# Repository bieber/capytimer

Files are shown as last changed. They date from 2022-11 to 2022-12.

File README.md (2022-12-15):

# CapyTimer

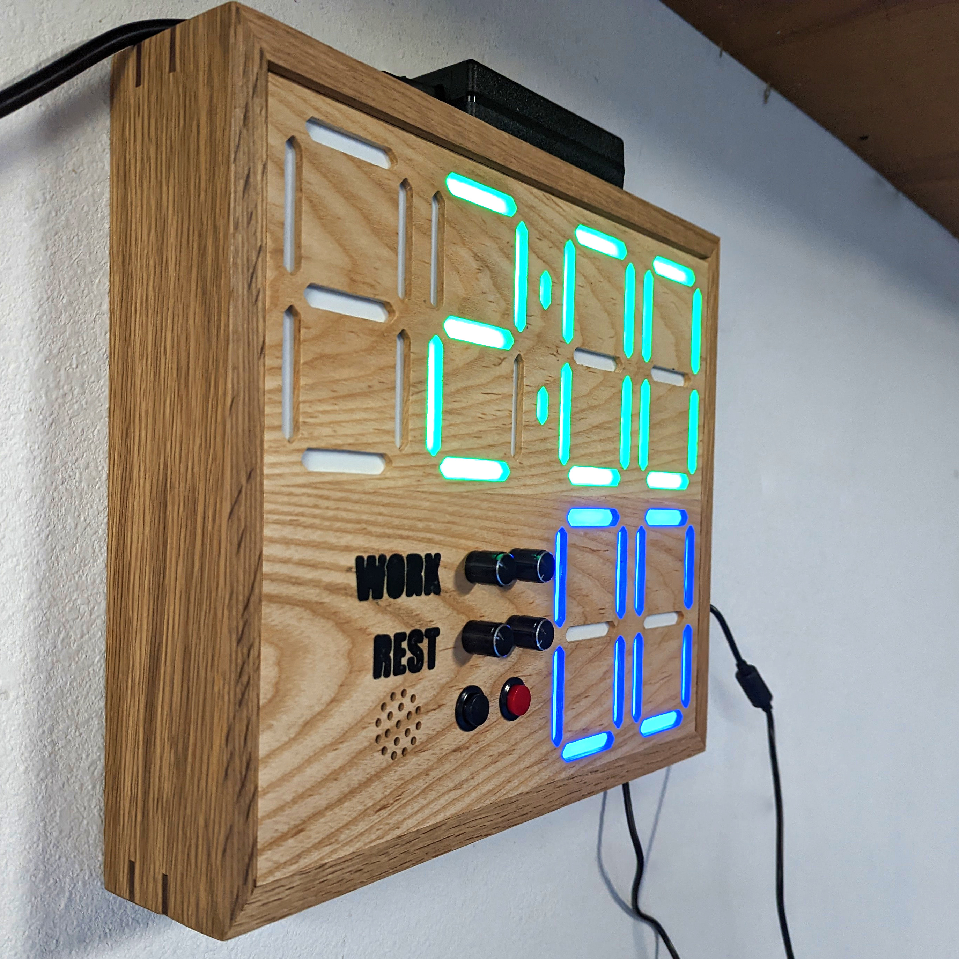
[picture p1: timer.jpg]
Photo of the completed timer


CapyTimer is meant to be a simple timer for
boxing/kickboxing/grappling/fitness.  My goal is to keep its interface
as simple as possible while maintaining the most important
functionality.  Work and rest times are set with dials, and the timing
started and stopped with a switch or button.  The display counts the
remaining time, the current round, and nothing else.

The display is constructed from WS2812B addressable LEDs.  The
original plan was to cut up and solder three-LED sections to create
the digits, but that proved time consuming and ugly so I ultimately
designed a PCB for the digits with the LEDs pre-placed.  You can
follow the original plan and save some money by cutting up and
soldering a WS2812B strip, or just order the PCBs preassembled from
JLC (or just get the boards manufactured and solder on the LEDs
yourself).

This isn't really meant to be a prescriptive set of instructions for
building the timer exactly a certain way.  I've provided components
here and I'll lay out a general path towards putting it together, but
you should feel free to substitute different controls and alter the
presentation to your liking.

**Warning** - The remote control design is currently untested.  I
*think* the parts will all fit properly, but I'm still waiting on the
final PCBs to test with and can't guarantee that the design works yet.

## Directory Structure

* `3d/` - Files for 3D printing.  These include the digit and
  separator diffusers, the remote control body, and a set of printed
  frames to hold the digits for testing purposes.
* `firmware/` - Code to run the AVR microcontroller.  Specifically
  this expects an Atmega328P, the avr-gcc toolchain and a USBasp
  programmer.  If you deviate from these specifications you may need
  to alter the firmware and makefile.
* `pcb/` - KiCad schematics and PCB designs.  This includes the main
  control board, boards with the LEDs laid out for the digits and
  separator, and a control board for the remote control.  With the
  exception of the remote control board (which is simple enough to
  easily hand solder), I've included gerbers and BOM/placement files
  that you can use to have the boards manufactured by JLCPCB.  These
  worked as of this publishing, but be warned that some parts may go
  out of stock and need replacing (they already switched to a new
  version of the WS2812B LEDs while I was working on the boards).
* `enclosure` - SVG designs to cut a front for the timer using the
  Shaper Origin.  You'll have to adapt these if you use a different
  CNC.

## Assembly Instructions

Please don't consider these instructions exhaustive, but more general
guidance.  You'll want to have some experience with electronics,
soldering and crimping connectors before getting started on this, as
well as some way to build an enclosure for the timer (I build mine out
of wood).

### Materials

| Part | Qty |
| ---- | --- |
| Control Board | 1 |
| Digit Board | 6 |
| Separator Board | 1 |
| Digit Diffuser | 6 |
| Separator Diffuser | 1 |
| M3x4.6x5.7mm Heat Set Inserts | 17 |
| M3x6 Screw | 14 |
| Linear Potentiometer (somewhere in the neighborhood of 10k) | 4 |
| Push Button | 2 |
| JST-PH Connector (3 pin) | 20 |
| JST-PH Connector (2 pin) | 4 |
| DC Barrel Connector | 1 |
| Right Angle Header (Female, 2.54mm) | 14 pins |
| Header (Male, 2.54mm) | 3 pins |
| Header Jumper | 1 |
| AVR-ISP 6 Pin Box Header | 1 |
| 3386P Potentiometer | 2 |
| 10k Through Hole Resistor | 2 |
| QIACHIP 433Mhz Transmitter/Receiver Set | 1 |
| Remote Control Parts | 1 set |
| M3x12 Screw | 3 |
| 5x1mm Round Magnet | 8 |
| AAA Battery Contact Plate | 4 |

Note that this doesn't include surface-mount components on the PCB,
only the parts you'll need to manually assemble.  If you intend to
hand solder the PCBs, consult the schematics for part listings.

### The Display

The display uses six digits and one separator between the minutes and
seconds.  You can have the digits and separator LEDs pre-assembled on
a PCB by JLCPCB using the files in the `pcb/` directory, or you can
buy a strip of WS2812B LEDs and glue them into the 3D printed
diffusers.  If you do so, you'll want to use 3 LEDs per digit segment
and one for each of the dots in the separator.  The LEDs should be
laid out in the same order that segments normally come in a seven
segment display.

If you get your LED PCBs pre-assembled, you'll still need to solder on
the connectors.  Use one three-pin JST-PH connector for each
connection.  Be sure to solder these on the back side of the board so
you can plug in to them while the front of the board is seated in the
diffuser.

When printing the plastic diffusers, I like to use white filament for
the first few layers and then switch to black.  This will minimize
light bleeding between segments while the display is in use.  If you
use PCBs for the digits and separator, the diffusers have holes for
threaded inserts.  You can then use the M3x6 screws to attach the
boards to the diffusers.

### The Control Board

Assuming you get the control board assembled by JLCPCB or some other
manufacturer, you'll just need to solder the connectors and a few
potentiometers onto the control board.  These include the DC barrel
jack for power, JST-PH connections for the screen, potentiometers and
push buttons, the AVR-ISP header, the header for the diagnostic jumper
(optional) and the angled header for the QIACHIP receiver module
(optional, only required if you want to use the remote control).  The
two 3386P potentiometers are used for volume and brightess control and
should be soldered directly onto the board.

The `JRESET1` connector is currently unused and can be safely ignored.

To program the microcontroller, just connect the ISP header to a
USBasp programmer.  You'll need the avr-gcc toolchain and avrdude
installed.  You can then run `make fuse` to program the fuses on the
chip, and `make program` to transfer the firmware.  After that the
timer should just work when everything is plugged in.

### Connections

* Solder a DC barrel jack connector onto `J1` for power.
* Connect four potentiometers to the 3-pin JST-PH connectors on the
  top-left corner of the board.  These will set the minutes and
  seconds for the work and rest periods.  The names on the silk screen
  are abbreviations for the function of the potentiometer, e.g. `JWM1`
  is the connection for the potentiometer that controls the minutes of
  the work period.  For these connectors, pin 1 is ground, pin 2 is
  signal, and pin 3 is +5v.
* The display connects to `JOUT1` and `JOUT2` via 3-pin JST-PH
  connectors.  Pin 1 is ground, pin 2 is signal, pin 3 is +5v.  As
  long as you connect the same pins on each end of your cables
  everything should work.  The WS2812B LEDs are daisy chained, so
  `JOUT1` should connect to the `JIN1` connector of the first digit,
  then its `JOUT1` connector should connect to the `JOUT1` of the next
  digit, and so on.  Connect the digits and separator for the time
  first, and then the two digits for the round display.  Finally, you
  can connect `JOUT1` on the last digit to `JOUT2` on the control
  board.  This final connection is for power only, to reduce the
  current that needs to flow through the first connection between
  control board and digits.
* The start and stop buttons should connect to the 2-pin JST-PH
  connectors labeled `JSTART1` and `JSTOP1`.  `JRESET1` is unused.
  These connectors have no polarity, they just need to be normally
  open and close when the buttons are pushed.
* Connect an active piezo buzzer to the 2-pin JST-PH connector labeled
  `JBUZZ1`.
* You may optionally solder a 3 pin male header to `JDIAG1`.  Place a
  jumper across the right two pins for normal operation: shifting the
  jumper to the left will put the timer in diagnostic mode, which
  displays the raw ADC value from the work minutes potentiometer for
  debugging purposes.
* If you intend to use a remote control, solder 7 pin female header,
  preferably right-angle, to `JRF1`.  You can then insert a QIACHIP
  receiver module directly into the header.

### Enclosure

The enclosure is largely left as an exercise for the reader.  You'll
want to select potentiometers and push buttons that fit your desired
aesthetic, and you may also wish to add features like an on/off switch
and external power inlet to the enclosure.

Because of the size of the timer, I haven't included a 3D printed
enclosure design.  Even with a 400x400 print bed, it would be
prohibitive to fit all six digits and the controls.  I have, however,
included two 3D printed frames that can hold the digit diffusers up
(with CA glue).  These aren't suitable for production use, but served
me well during development.

For production use, I build my enclosures as open-backed wooden boxes
with a front panel that has pockets routed in for the digit diffusers,
controls and the piezo buzzer.  I use a Shaper Origin to make the cuts
in the front panel, and you can find the SVG files for my design in
the `enclosure/` directory.  I've only tested these with the Shaper,
and expect that other CNCs will probably need some work to adapt them.

### Remote Control (Optional)

With a QIACHIP receiver and transmitter set, you can also build a
remote control for your timer.  The `pcb/` directory includes a small
PCB to tie the QIACIP transmitter to some tactile push button switches
and two AAA batteries.

For the remote control board, you'll need to solder on two pull-up
resistors, two tactile push-button switches (use switches tall enough
to poke up through the remote body), and a connector for the batteries
(or just solder the battery connectors directly to the board).  Add
right-angle header for the QIACHIP transmitter, and solder on an
antenna to `JANT1`.

The top remote component has holes for three heat-set inserts and four
5x1mm magnets, which should be glued into place.  You'll also want to
glue in the four battery contact plates, alternating positive and
negative plates between the two battery slots.  Solder the two plates
at the bottom of the remote together, and then solder wires on to the
connectors towards the top.

Glue opposite-polarity magnets into the remote lid to hold it on to
the body.  You can then attach the PCB and the remote body bottom to
the top by using the three M3x12 screws.  This connection is
inherently weak because the stems holding everything together are
stressed perpendicular to their layers, so be careful not to tighten
the screws more than necessary to hold everything together.

## Afterword

This should give you a rough idea of how to assemble one of these
timers, but the instructions aren't exceedingly detailed and leave a
lot of room to make the project your own.  If you attempt to build one
and run into problems, feel free to submit an issue.  And if you come
up with a design improvement, pull requests are welcome.

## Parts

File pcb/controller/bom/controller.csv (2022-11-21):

Comment | Designator | Footprint | LCSC
.1uF | C1 | Capacitor_SMD:C_0603_1608Metric | C14663
10uF | C2 | Capacitor_SMD:C_0805_2012Metric | C15850
22pF | C3,C4 | Capacitor_SMD:C_0402_1005Metric | C1555
LED | D1,D2,D3,D4,D5 | LED_SMD:LED_0805_2012Metric | C2297
Barrel_Jack | J1 | Connector_BarrelJack:BarrelJack_Horizontal
AVR-ISP-6 | J2 | Connector_IDC:IDC-Header_2x03_P2.54mm_Vertical
Conn_01x01 | JANT1 | Connector_PinHeader_2.54mm:PinHeader_1x01_P2.54mm_Vertical
Conn_01x02_Male | JBUZZ1,JRESET1,JSTART1,JSTOP1 | Connector_JST:JST_PH_B2B-PH-K_1x02_P2.00mm_Vertical
Conn_01x03_Male | JDIAG1 | Connector_PinHeader_2.54mm:PinHeader_1x03_P2.54mm_Vertical
Conn_01x03_Male | JOUT1,JRM1,JRS1,JWM1,JWS1,JOUT2 | Connector_JST:JST_PH_B3B-PH-K_1x03_P2.00mm_Vertical
Conn_01x07_Female | JRF1 | Connector_PinHeader_2.54mm:PinHeader_1x07_P2.54mm_Vertical
2N7002 | Q1 | Package_TO_SOT_SMD:SOT-23 | C8545
1kΩ | R1,R6,R7,R8,R9 | Resistor_SMD:R_0603_1608Metric | C21190
10kΩ | R2,R3,R4,R5 | Resistor_SMD:R_0603_1608Metric | C25804
R_Potentiometer | RVBRIGHT1,RVVOL1 | Potentiometer_THT:Potentiometer_Bourns_3386P_Vertical
ATmega328P-A | U1 | Package_QFP:TQFP-32_7x7mm_P0.8mm | C14877
Crystal_GND24 | Y1 | Crystal:Crystal_SMD_3225-4Pin_3.2x2.5mm | C431155

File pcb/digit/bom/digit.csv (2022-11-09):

Comment | Designator | Footprint | LCSC
WS2812B | D1,D2,D3,D4,D5,D6,D7,D8,D9,D10,D11,D12,D13,D14,D15,D16,D17,D18,D19,D20,D21 | LED_SMD:LED_WS2812B_PLCC4_5.0x5.0mm_P3.2mm | C2874885
Conn_01x03_Male | JIN1,JOUT1 | Connector_JST:JST_PH_B3B-PH-K_1x03_P2.00mm_Vertical

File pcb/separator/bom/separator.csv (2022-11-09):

Comment | Designator | Footprint | LCSC
WS2812B | D1,D2 | LED_SMD:LED_WS2812B_PLCC4_5.0x5.0mm_P3.2mm | C2874885
Conn_01x03_Male | JIN1,JOUT1 | Connector_JST:JST_PH_B3B-PH-K_1x03_P2.00mm_Vertical

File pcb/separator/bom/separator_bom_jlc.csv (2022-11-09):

Comment | Designator | Footprint | LCSC
WS2812B | D1,D2 | LED_WS2812B_PLCC4_5.0x5.0mm_P3.2mm | C2874885

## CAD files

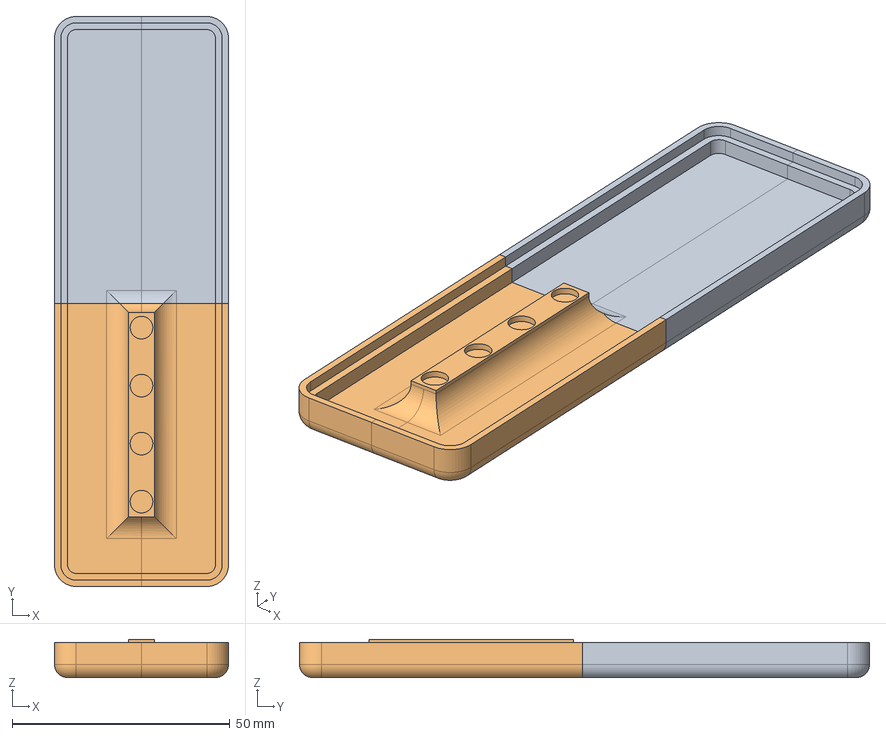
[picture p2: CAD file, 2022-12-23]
3d/remote.FCStd
40.0 x 131.0 x 8.75 mm
Fixed
Lid

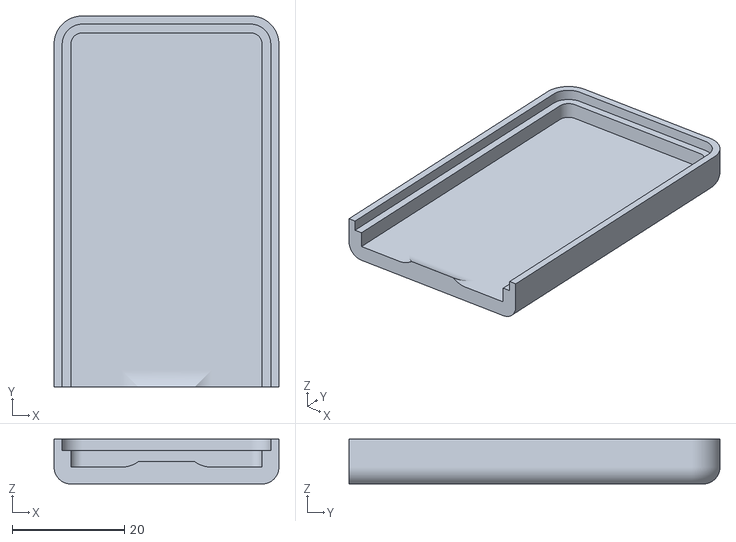
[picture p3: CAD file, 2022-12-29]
3d/stl/remote/bottom.stl
40.0 x 66.0 x 8.00

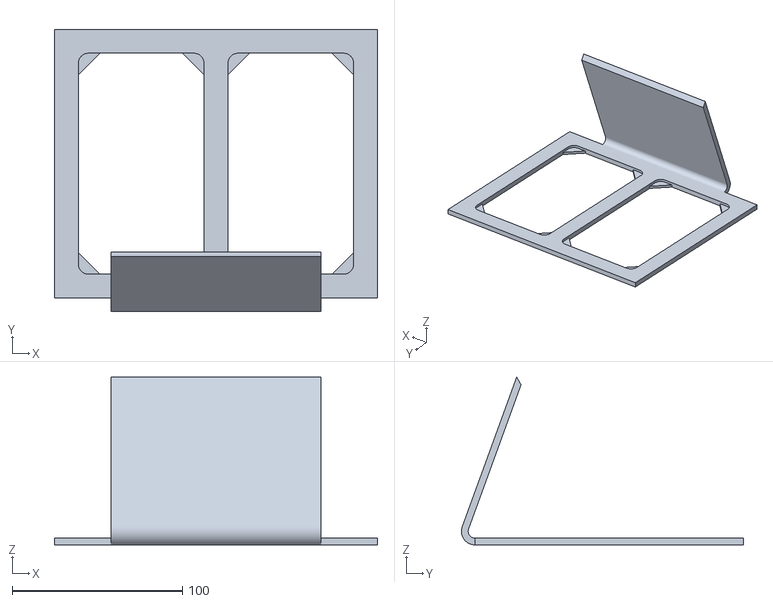
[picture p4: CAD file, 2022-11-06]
3d/stl/round_frame.stl
190.0 x 166.0 x 98.7

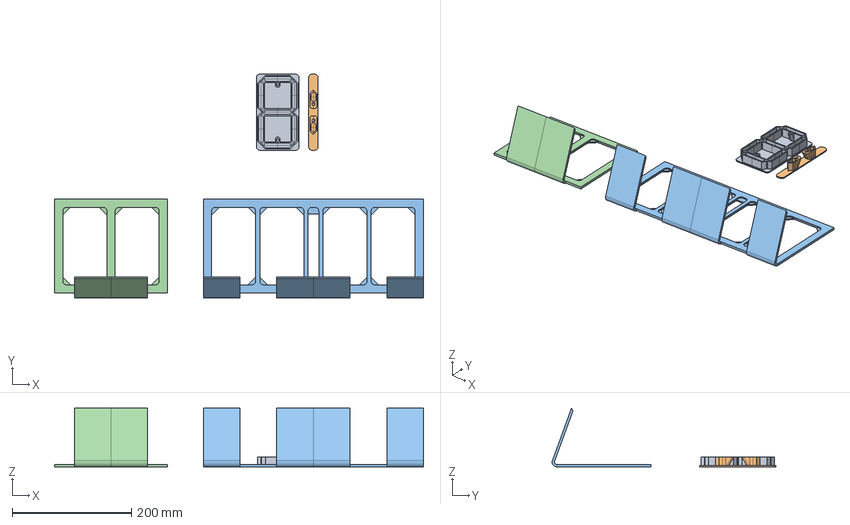
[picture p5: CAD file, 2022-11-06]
3d/capytimer.FCStd
620.0 x 376.0 x 98.7 mm
Digit
Divider
Time Frame
Round Frame

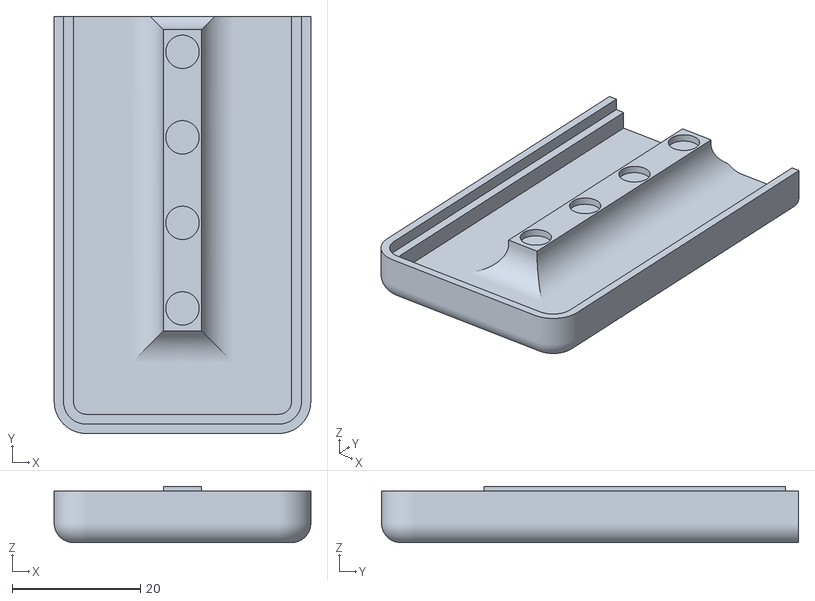
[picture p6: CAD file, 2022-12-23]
3d/stl/remote/lid.stl
40.0 x 65.0 x 8.75

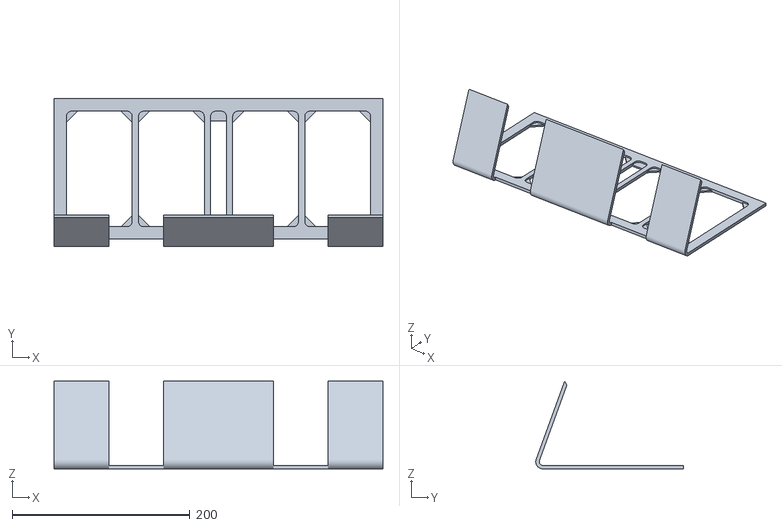
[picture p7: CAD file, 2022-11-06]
3d/stl/time_frame.stl
370.0 x 166.0 x 98.7

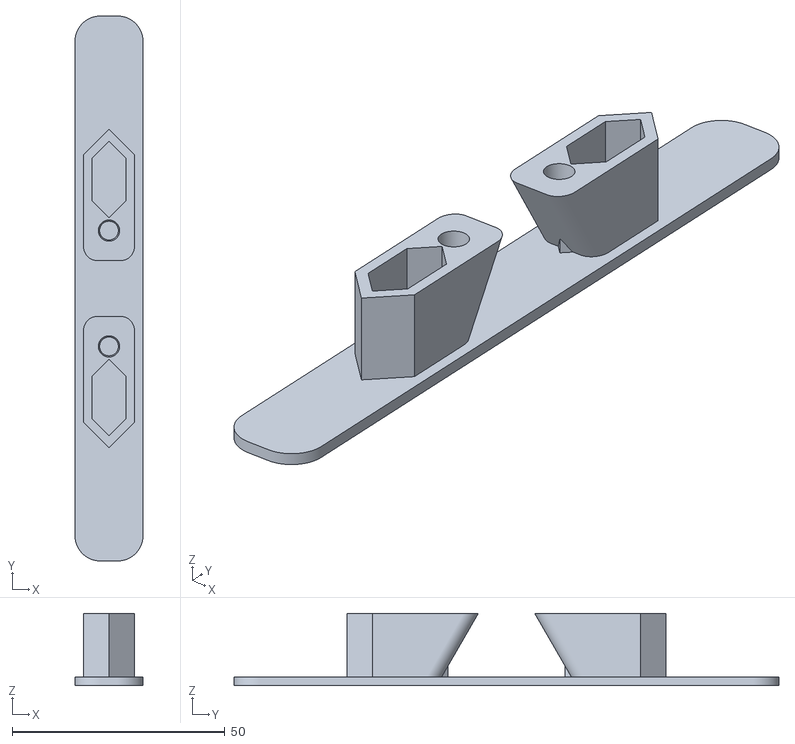
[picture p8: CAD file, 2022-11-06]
3d/stl/divider.stl
16.0 x 128.0 x 17.0

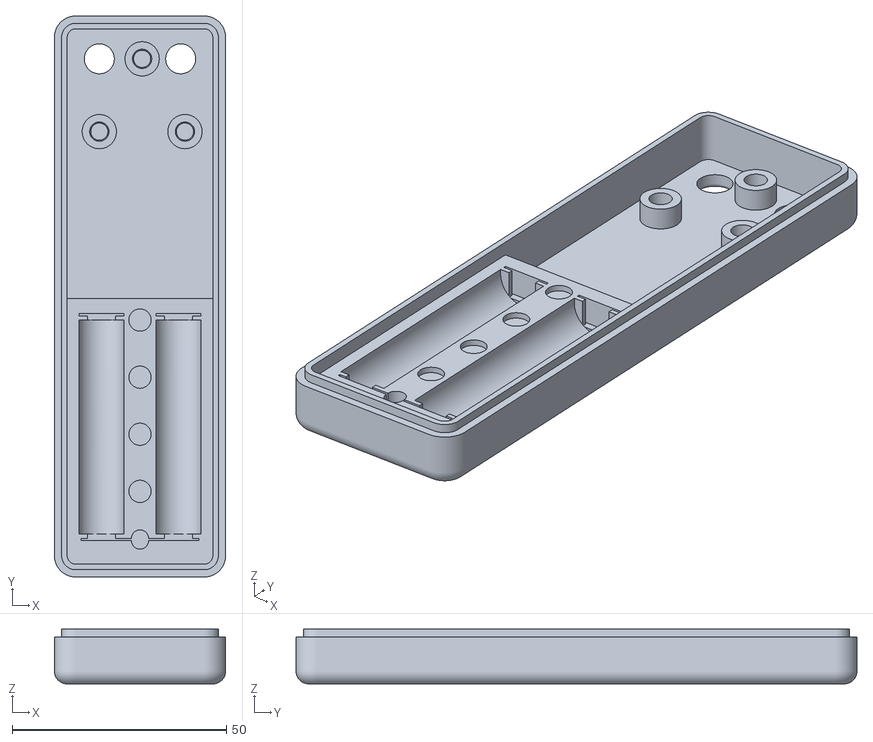
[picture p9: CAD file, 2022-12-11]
3d/stl/remote/top.stl
40.0 x 131.0 x 12.8

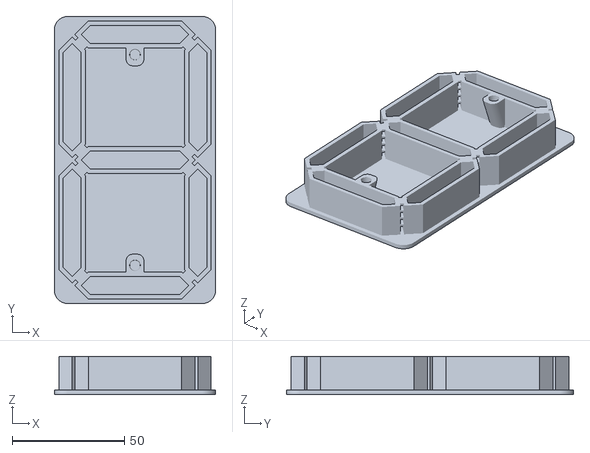
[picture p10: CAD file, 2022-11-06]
3d/stl/digit.stl
72.0 x 128.0 x 17.0

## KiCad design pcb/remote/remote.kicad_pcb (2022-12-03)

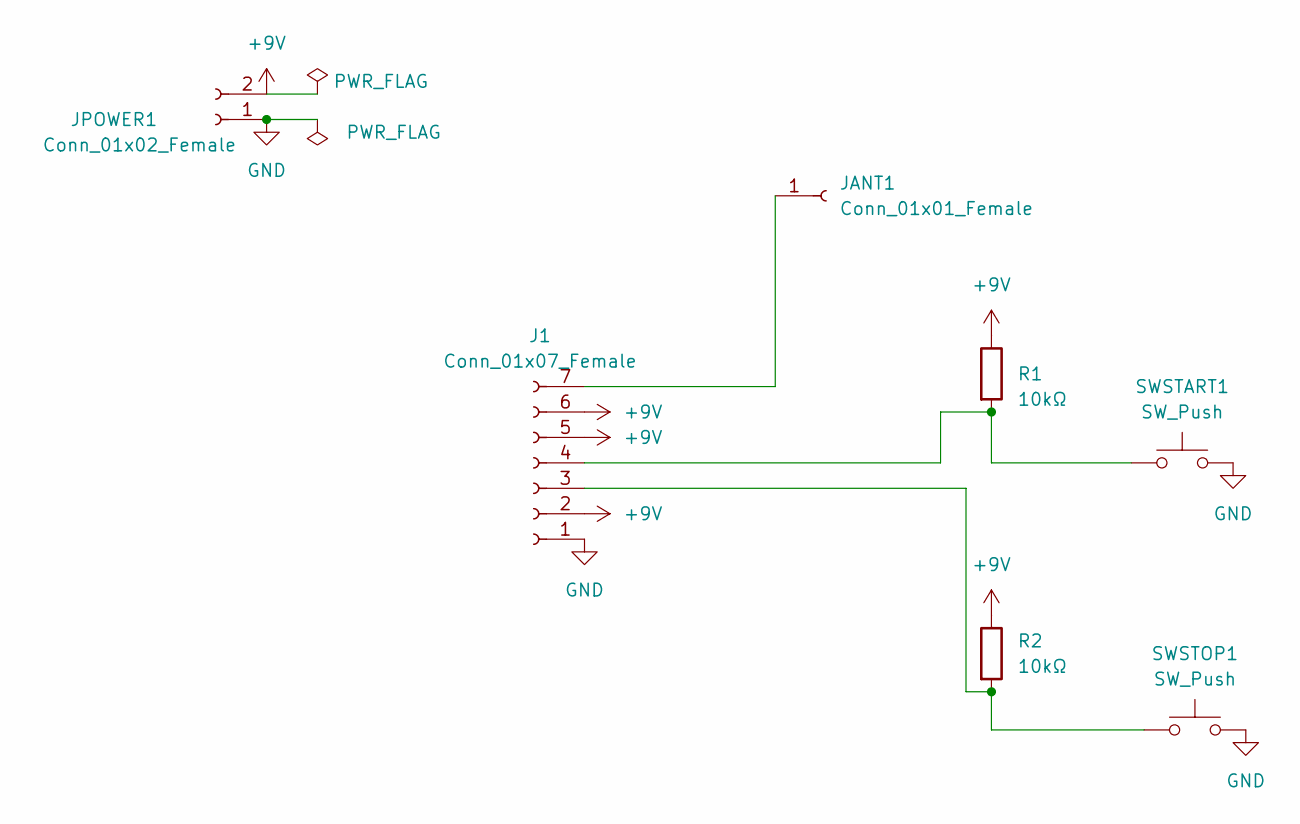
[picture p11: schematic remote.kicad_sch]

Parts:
J1: Conn_01x07_Female; PinHeader_1x07_P2.54mm_Vertical
JANT1: Conn_01x01_Female; PinHeader_1x01_P2.54mm_Vertical
JPOWER1: Conn_01x02_Female; JST_PH_B2B-PH-K_1x02_P2.00mm_Vertical
R1, R2: 10kΩ; R_Axial_DIN0207_L6.3mm_D2.5mm_P10.16mm_Horizontal; LCSC C25804
SWSTART1: SW_Push; SW_PUSH_6mm
SWSTOP1: SW_Push; SW_PUSH_6mm

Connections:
+9V: J1.2, J1.5, J1.6, JPOWER1.2, R1.1, R2.1
GND: J1.1, JPOWER1.1, SWSTART1.2, SWSTOP1.2
unnamed: J1.3, R2.2, SWSTOP1.1
unnamed: J1.4, R1.2, SWSTART1.1
unnamed: J1.7, JANT1.1

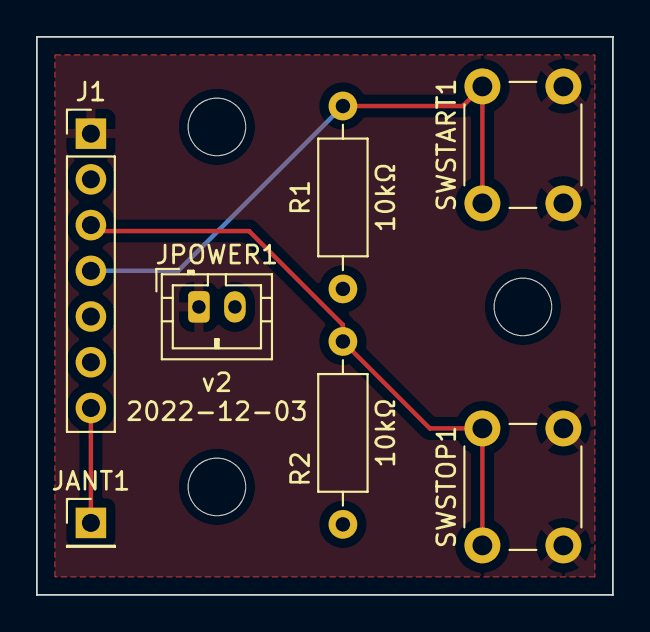
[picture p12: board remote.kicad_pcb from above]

Board: 2 copper layers, 32.0 x 31.0 mm, 7 parts (0 on the bottom side), 5 nets.

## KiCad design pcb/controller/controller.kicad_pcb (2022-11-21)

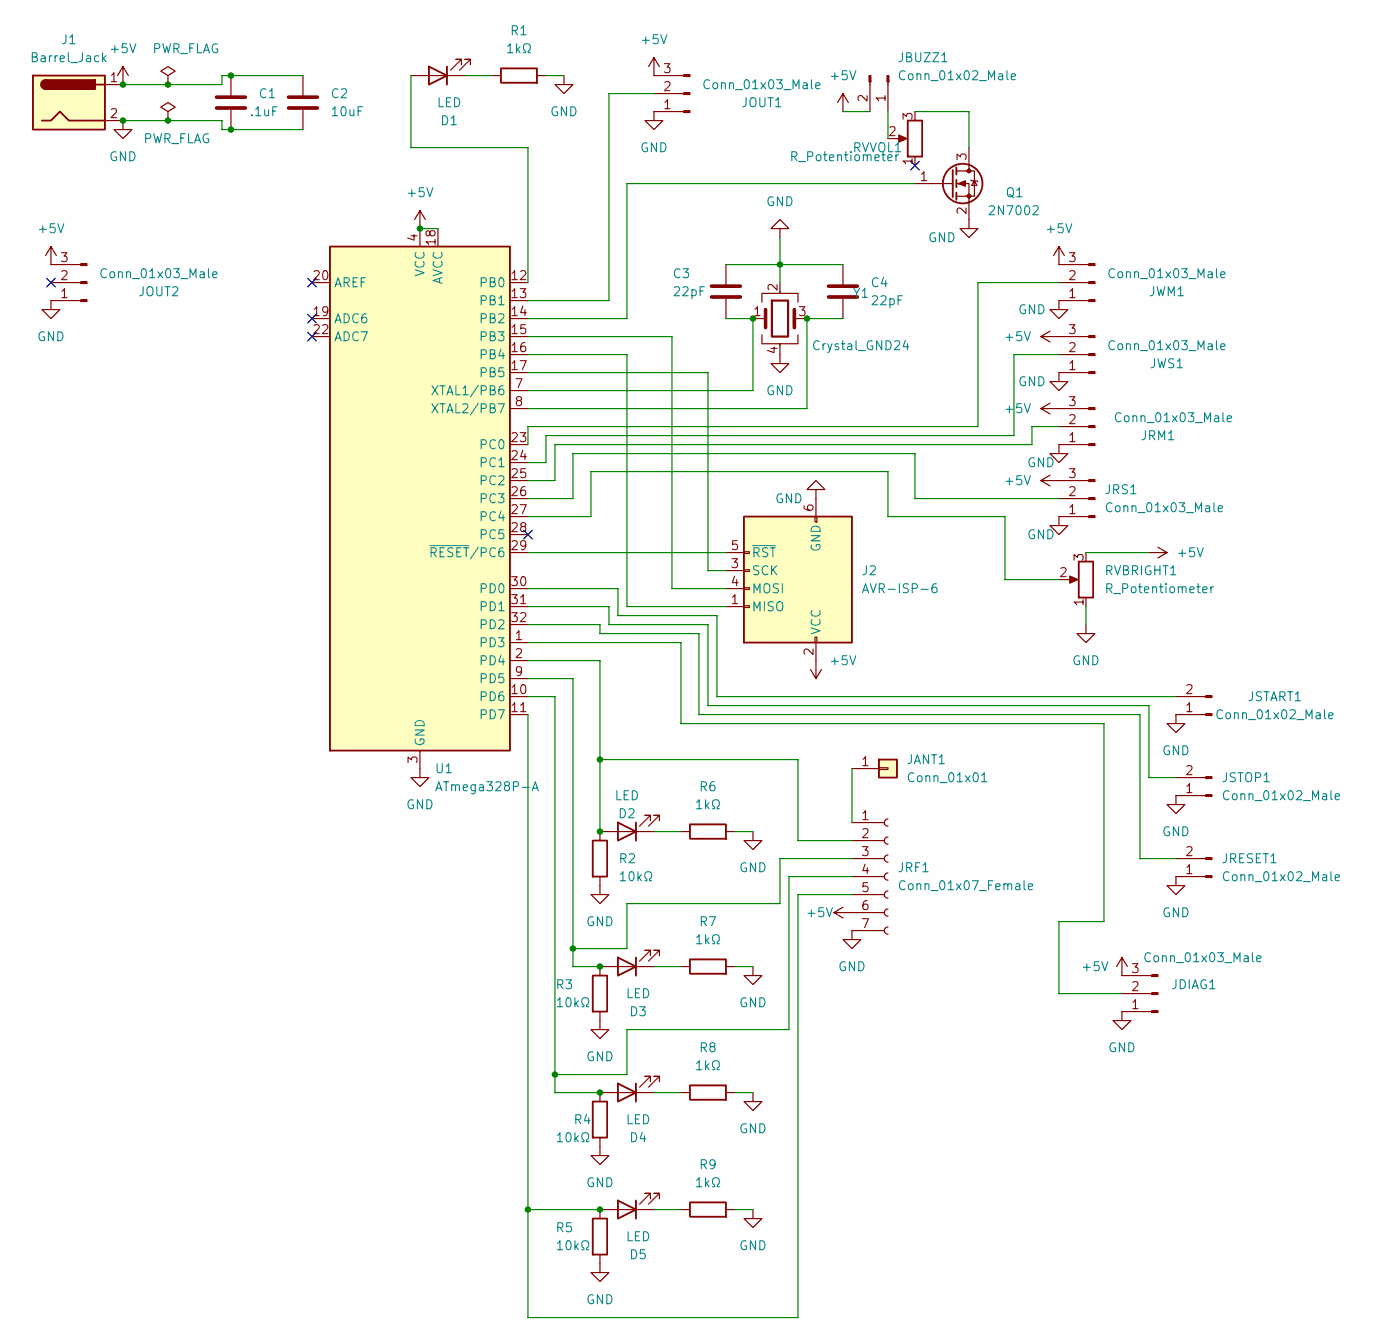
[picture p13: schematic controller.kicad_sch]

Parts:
C1: .1uF; C_0603_1608Metric; LCSC C14663
C2: 10uF; C_0805_2012Metric; LCSC C15850
C3, C4: 22pF; C_0402_1005Metric; LCSC C1555
D1, D2, D3, D4, D5: LED; LED_0805_2012Metric; LCSC C2297
J1: Barrel_Jack; BarrelJack_Horizontal
J2: AVR-ISP-6; IDC-Header_2x03_P2.54mm_Vertical
JANT1: Conn_01x01; PinHeader_1x01_P2.54mm_Vertical
JBUZZ1: Conn_01x02_Male; JST_PH_B2B-PH-K_1x02_P2.00mm_Vertical
JDIAG1: Conn_01x03_Male; PinHeader_1x03_P2.54mm_Vertical
JOUT1, JOUT2: Conn_01x03_Male; JST_PH_B3B-PH-K_1x03_P2.00mm_Vertical
JRESET1: Conn_01x02_Male; JST_PH_B2B-PH-K_1x02_P2.00mm_Vertical
JRF1: Conn_01x07_Female; PinHeader_1x07_P2.54mm_Vertical
JRM1: Conn_01x03_Male; JST_PH_B3B-PH-K_1x03_P2.00mm_Vertical
JRS1: Conn_01x03_Male; JST_PH_B3B-PH-K_1x03_P2.00mm_Vertical
JSTART1: Conn_01x02_Male; JST_PH_B2B-PH-K_1x02_P2.00mm_Vertical
JSTOP1: Conn_01x02_Male; JST_PH_B2B-PH-K_1x02_P2.00mm_Vertical
JWM1: Conn_01x03_Male; JST_PH_B3B-PH-K_1x03_P2.00mm_Vertical
JWS1: Conn_01x03_Male; JST_PH_B3B-PH-K_1x03_P2.00mm_Vertical
Q1: 2N7002; SOT-23; LCSC C8545
R1, R6, R7, R8, R9: 1kΩ; R_0603_1608Metric; LCSC C21190
R2, R3, R4, R5: 10kΩ; R_0603_1608Metric; LCSC C25804
RVBRIGHT1: R_Potentiometer; Potentiometer_Bourns_3386P_Vertical
RVVOL1: R_Potentiometer; Potentiometer_Bourns_3386P_Vertical
U1: ATmega328P-A; TQFP-32_7x7mm_P0.8mm; LCSC C14877
Y1: Crystal_GND24; Crystal_SMD_3225-4Pin_3.2x2.5mm; LCSC C431155

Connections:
+5V: C1.1, C2.1, J1.1, J2.2 (VCC), JBUZZ1.2, JDIAG1.3, JOUT1.3, JOUT2.3, JRF1.6, JRM1.3, JRS1.3, JWM1.3, JWS1.3, RVBRIGHT1.3, U1.4 (VCC), U1.6 (VCC), U1.18 (AVCC)
GND: C1.2, C2.2, C3.1, C4.1, J1.2, J2.6 (GND), JDIAG1.1, JOUT1.1, JOUT2.1, JRESET1.1, JRF1.7, JRM1.1, JRS1.1, JSTART1.1, JSTOP1.1, JWM1.1, JWS1.1, Q1.2 (S), R1.2, R2.2, R3.2, R4.2, R5.2, R6.2, R7.2, R8.2, R9.2, RVBRIGHT1.1, U1.3 (GND), U1.5 (GND), U1.21 (GND), Y1.2, Y1.4
unnamed: C3.2, U1.7 (XTAL1/PB6), Y1.1
unnamed: C4.2, U1.8 (XTAL2/PB7), Y1.3
unnamed: D1.1 (K), R1.1
unnamed: D1.2 (A), U1.12 (PB0)
unnamed: D2.1 (K), R6.1
unnamed: D2.2 (A), JRF1.2, R2.1, U1.2 (PD4)
unnamed: D3.1 (K), R7.1
unnamed: D3.2 (A), JRF1.3, R3.1, U1.9 (PD5)
unnamed: D4.1 (K), R8.1
unnamed: D4.2 (A), JRF1.4, R4.1, U1.10 (PD6)
unnamed: D5.1 (K), R9.1
unnamed: D5.2 (A), JRF1.5, R5.1, U1.11 (PD7)
unnamed: J2.1 (MISO), U1.16 (PB4)
unnamed: J2.3 (SCK), U1.17 (PB5)
unnamed: J2.4 (MOSI), U1.15 (PB3)
unnamed: J2.5 (~RST), U1.29 (~RESET/PC6)
unnamed: JANT1.1, JRF1.1
unnamed: JBUZZ1.1, RVVOL1.2
unnamed: JDIAG1.2, U1.1 (PD3)
unnamed: JOUT1.2, U1.13 (PB1)
unnamed: JRESET1.2, U1.32 (PD2)
unnamed: JRM1.2, U1.25 (PC2)
unnamed: JRS1.2, U1.26 (PC3)
unnamed: JSTART1.2, U1.30 (PD0)
unnamed: JSTOP1.2, U1.31 (PD1)
unnamed: JWM1.2, U1.23 (PC0)
unnamed: JWS1.2, U1.24 (PC1)
unnamed: Q1.1 (G), U1.14 (PB2)
unnamed: Q1.3 (D), RVVOL1.3
unnamed: RVBRIGHT1.2, U1.27 (PC4)

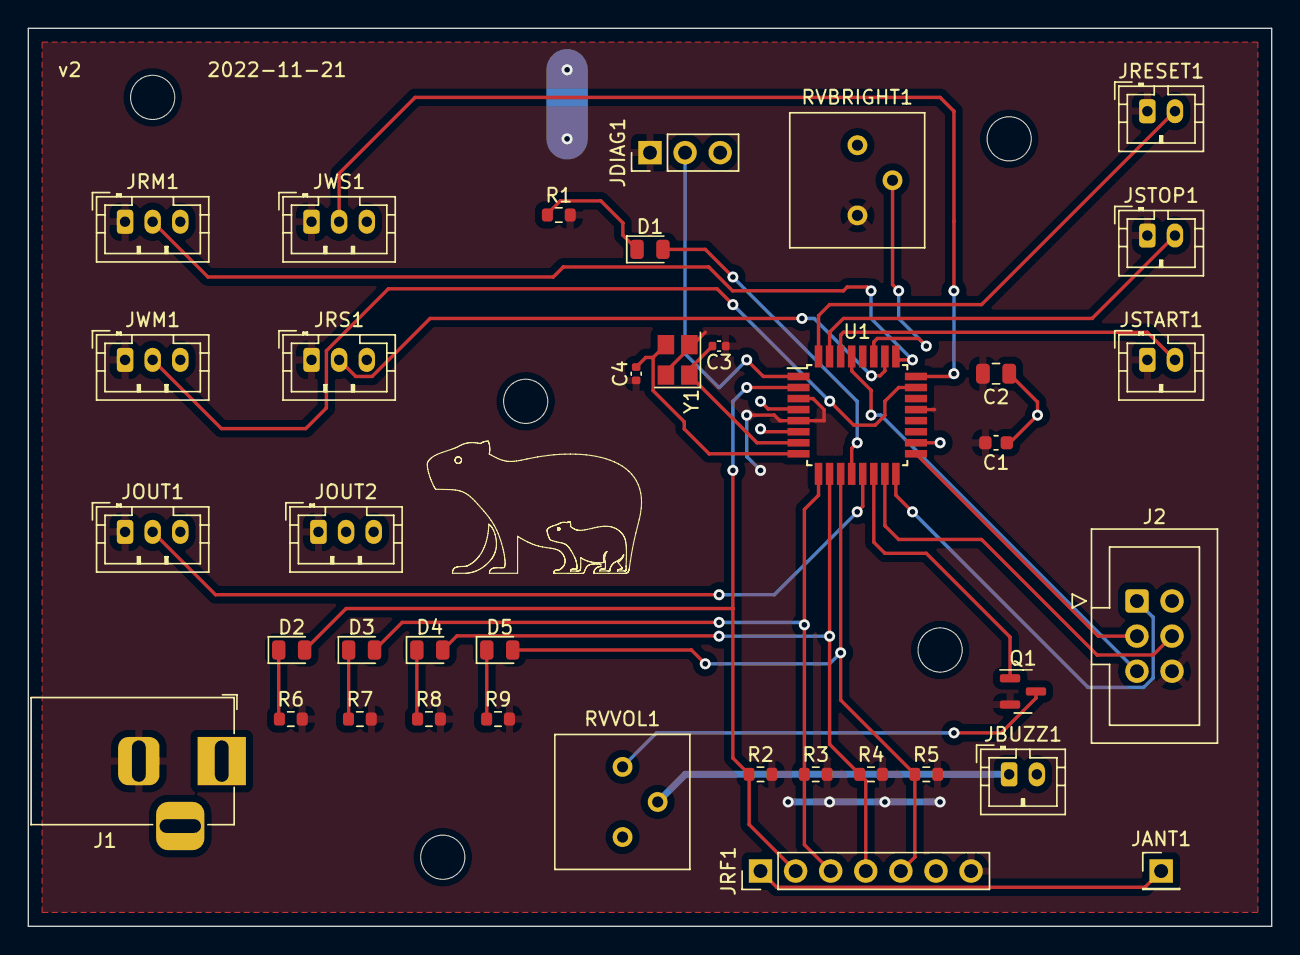
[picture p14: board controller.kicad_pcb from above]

Board: 2 copper layers, 90.0 x 65.0 mm, 38 parts (0 on the bottom side), 32 nets.

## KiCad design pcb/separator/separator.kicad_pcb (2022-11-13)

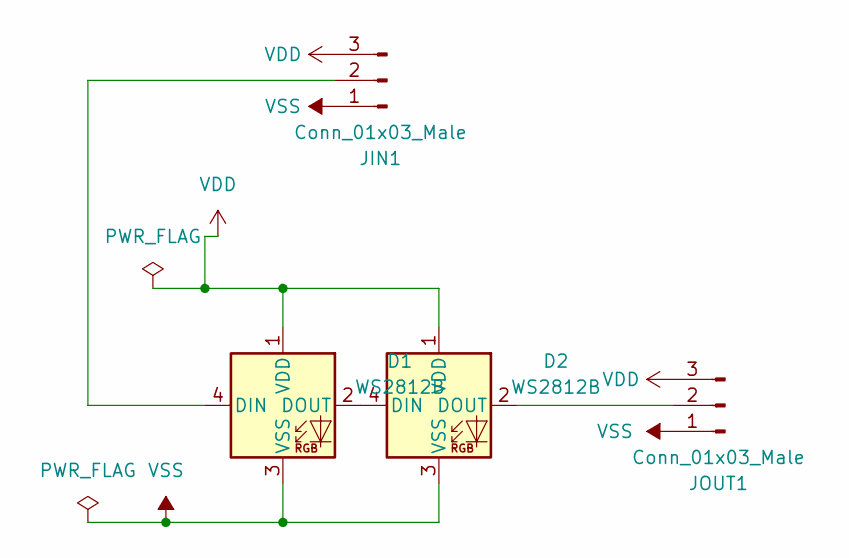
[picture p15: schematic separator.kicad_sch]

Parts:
D1, D2: WS2812B; LED_WS2812B_PLCC4_5.0x5.0mm_P3.2mm; LCSC C2874885
JIN1: Conn_01x03_Male; JST_PH_B3B-PH-K_1x03_P2.00mm_Vertical
JOUT1: Conn_01x03_Male; JST_PH_B3B-PH-K_1x03_P2.00mm_Vertical

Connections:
unnamed: D1.2 (DOUT), D2.4 (DIN)
unnamed: D1.4 (DIN), JIN1.2
unnamed: D2.2 (DOUT), JOUT1.2
VDD: D1.1 (VDD), D2.1 (VDD), JIN1.3, JOUT1.3
VSS: D1.3 (VSS), D2.3 (VSS), JIN1.1, JOUT1.1

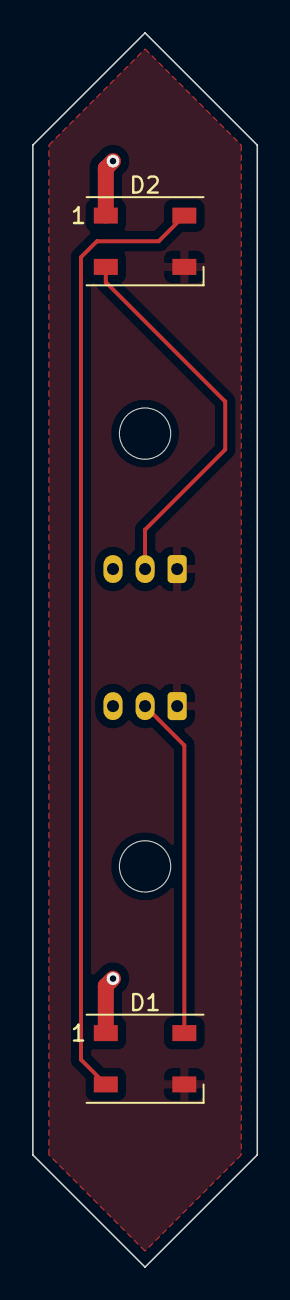
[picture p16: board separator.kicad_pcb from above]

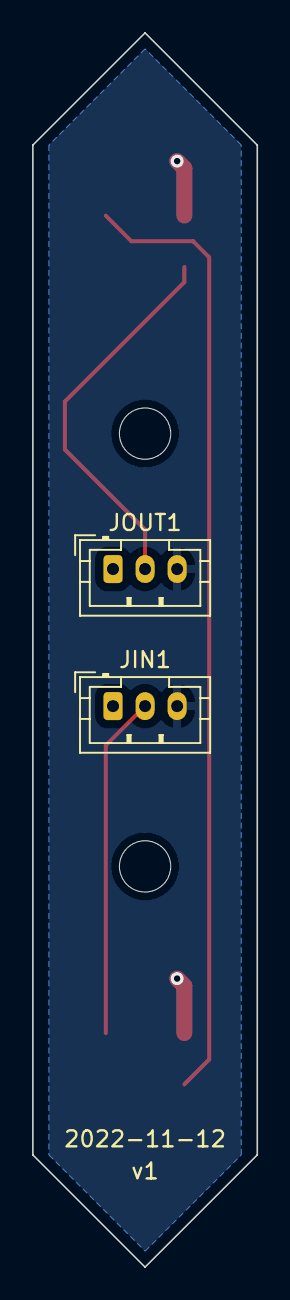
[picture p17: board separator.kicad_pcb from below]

Board: 2 copper layers, 14.0 x 77.0 mm, 4 parts (2 on the bottom side), 5 nets.

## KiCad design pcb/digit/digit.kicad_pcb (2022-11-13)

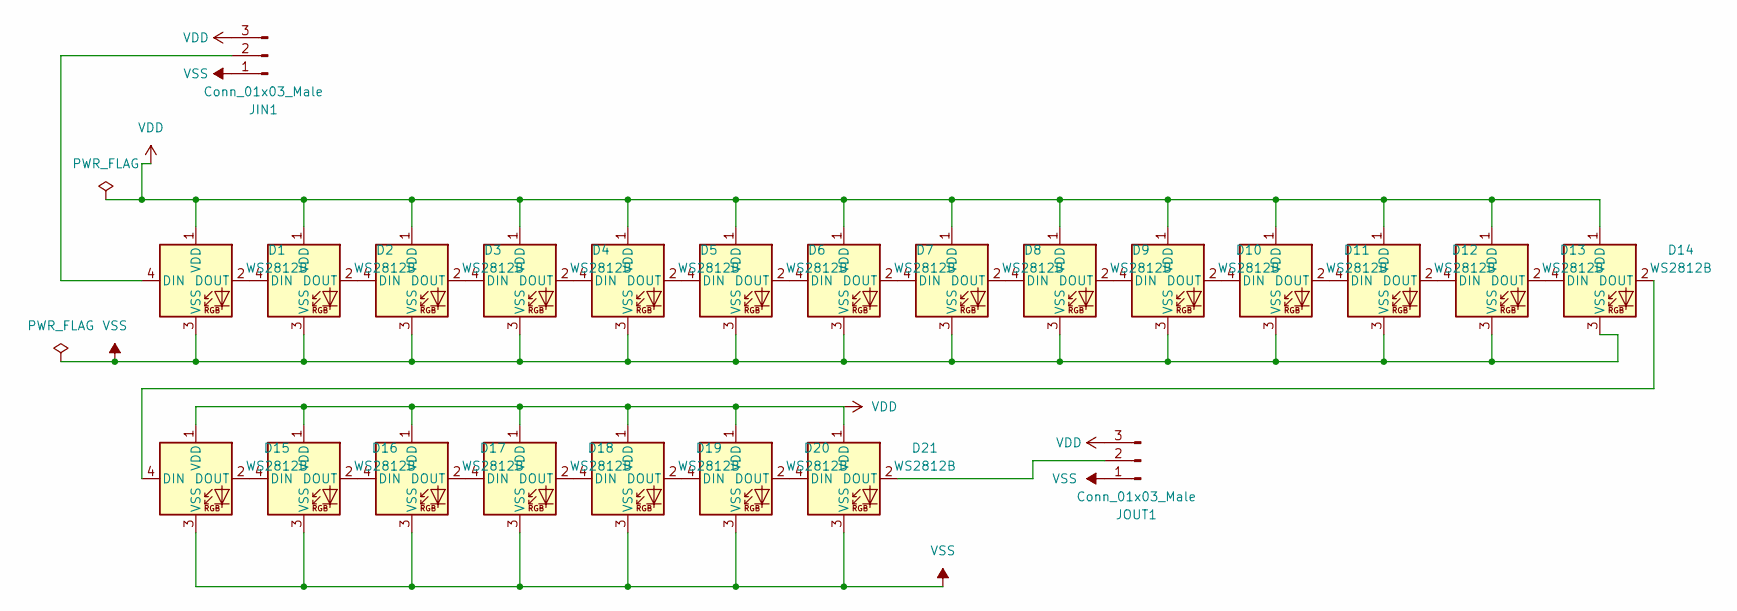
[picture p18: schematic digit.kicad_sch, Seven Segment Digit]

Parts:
D1, D2, D3, D4, D5, D6, D7, D8, D9, D10, D11, D12, D13, D14, D15, D16, D17, D18, D19, D20, D21: WS2812B; LED_WS2812B_PLCC4_5.0x5.0mm_P3.2mm; LCSC C2874885
JIN1: Conn_01x03_Male; JST_PH_B3B-PH-K_1x03_P2.00mm_Vertical
JOUT1: Conn_01x03_Male; JST_PH_B3B-PH-K_1x03_P2.00mm_Vertical

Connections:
unnamed: D1.2 (DOUT), D2.4 (DIN)
unnamed: D1.4 (DIN), JIN1.2
unnamed: D2.2 (DOUT), D3.4 (DIN)
unnamed: D3.2 (DOUT), D4.4 (DIN)
unnamed: D4.2 (DOUT), D5.4 (DIN)
unnamed: D5.2 (DOUT), D6.4 (DIN)
unnamed: D6.2 (DOUT), D7.4 (DIN)
unnamed: D7.2 (DOUT), D8.4 (DIN)
unnamed: D8.2 (DOUT), D9.4 (DIN)
unnamed: D10.2 (DOUT), D11.4 (DIN)
unnamed: D9.2 (DOUT), D10.4 (DIN)
unnamed: D11.2 (DOUT), D12.4 (DIN)
unnamed: D12.2 (DOUT), D13.4 (DIN)
unnamed: D13.2 (DOUT), D14.4 (DIN)
unnamed: D14.2 (DOUT), D15.4 (DIN)
unnamed: D15.2 (DOUT), D16.4 (DIN)
unnamed: D16.2 (DOUT), D17.4 (DIN)
unnamed: D17.2 (DOUT), D18.4 (DIN)
unnamed: D18.2 (DOUT), D19.4 (DIN)
unnamed: D19.2 (DOUT), D20.4 (DIN)
unnamed: D20.2 (DOUT), D21.4 (DIN)
unnamed: D21.2 (DOUT), JOUT1.2
VDD: D1.1 (VDD), D2.1 (VDD), D3.1 (VDD), D4.1 (VDD), D5.1 (VDD), D6.1 (VDD), D7.1 (VDD), D8.1 (VDD), D9.1 (VDD), D10.1 (VDD), D11.1 (VDD), D12.1 (VDD), D13.1 (VDD), D14.1 (VDD), D15.1 (VDD), D16.1 (VDD), D17.1 (VDD), D18.1 (VDD), D19.1 (VDD), D20.1 (VDD), D21.1 (VDD), JIN1.3, JOUT1.3
VSS: D1.3 (VSS), D2.3 (VSS), D3.3 (VSS), D4.3 (VSS), D5.3 (VSS), D6.3 (VSS), D7.3 (VSS), D8.3 (VSS), D9.3 (VSS), D10.3 (VSS), D11.3 (VSS), D12.3 (VSS), D13.3 (VSS), D14.3 (VSS), D15.3 (VSS), D16.3 (VSS), D17.3 (VSS), D18.3 (VSS), D19.3 (VSS), D20.3 (VSS), D21.3 (VSS), JIN1.1, JOUT1.1

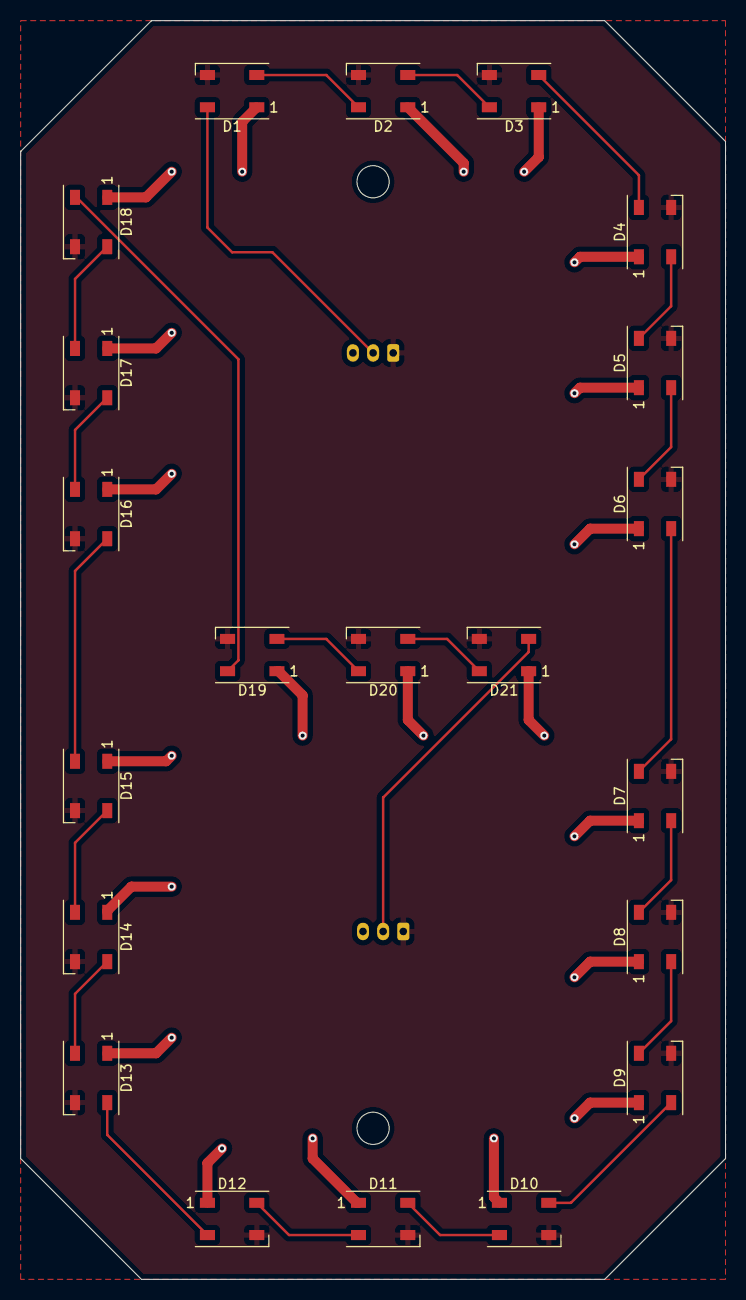
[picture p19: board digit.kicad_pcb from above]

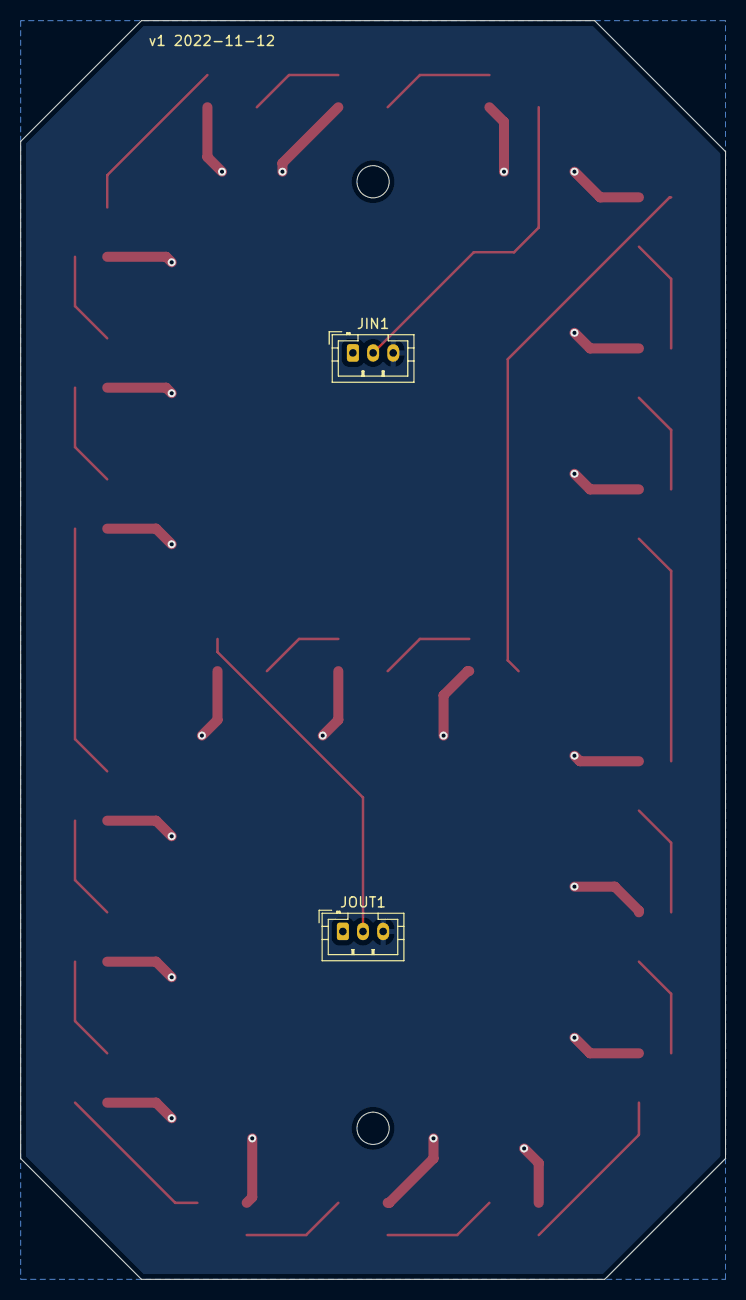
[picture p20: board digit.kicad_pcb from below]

Board: 2 copper layers, 70.0 x 125.0 mm, 23 parts (2 on the bottom side), 24 nets.

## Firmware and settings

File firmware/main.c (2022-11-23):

/*
 * Copyright (C) 2022, Robert Bieber
 *
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
 * You should have received a copy of the GNU General Public License
 * along with this program.  If not, see
 * <https://www.gnu.org/licenses/>.
 */

#define F_CPU 20000000L

#include <util/delay.h>
#include <avr/interrupt.h>
#include <avr/io.h>

#include "adc.h"
#include "debounce.h"
#include "digits.h"
#include "pins.h"
#include "setup.h"
#include "time.h"
#include "write_pixels.h"

#define REST_DISPLAY_TIME_MS 5000
#define BUZZ_TIME_REST_MS 800
#define BUZZ_TIME_WORK_MS 1000
#define BUZZ_ALTERNATE_MS 40

enum State {STARTUP, WORK, REST, PAUSE};

struct Time work_time = {0, 0};
struct Time rest_time = {0, 0};
uint8_t brightness = 0;

volatile struct Time running_time = {0, 0};
volatile uint8_t current_round = 0;

volatile uint16_t display_rest_cycles = 0;

volatile uint16_t buzz_cycles = 0;
volatile uint16_t buzz_alternate_cycles = 0;
volatile uint8_t buzz_alternate = 0;

volatile enum State state = STARTUP;
volatile enum State paused_state;

void start();
void pause();
void resume();
void reset();
void advance_state();

void buzz_work();
void buzz_rest();
void buzz_off();

int main(void) {
	uint8_t pixels[SCREEN_SIZE];
	setup(pixels);

	uint8_t initial_time_set = 0;

	struct Time new_work;
	struct Time new_rest;

	while (1) {
		brightness = debounce_brightness(brightness, ADC_BRIGHTNESS);
		uint8_t time_set = 0;

		if (!(PORT_DIAGNOSTIC & (1 << PIN_DIAGNOSTIC))) {
			// In diagnostic mode, we just display the raw value from
			// the work minutes potentiometer.  We can use this to
			// profile dials for the final product
			set_number(pixels, read_adc(ADC_WORK_MINUTES), 255, 255, 255);
			write_pixels(pixels, sizeof(pixels));
			_delay_ms(250);
			continue;
		}

		switch (state) {
		case STARTUP:
			new_work = debounce_time(
				work_time,
				ADC_WORK_MINUTES,
				ADC_WORK_SECONDS
			);
			if (!time_eq(new_work, work_time)) {
				work_time = new_work;
				TCCR0B &= TIMER_0_OFF;
				display_rest_cycles = 0;
			}

			new_rest = debounce_time(
				rest_time,
				ADC_REST_MINUTES,
				ADC_REST_SECONDS
			);
			if (!time_eq(new_rest, rest_time)) {
				rest_time = new_rest;
				if (initial_time_set) {
					display_rest_cycles = REST_DISPLAY_TIME_MS / 10;
					TCCR0B |= TIMER_0_ON;
				}
			}

			if (!initial_time_set) {
				initial_time_set = 1;
			}
			if (display_rest_cycles > 0) {
				set_time(pixels, rest_time, brightness, 0, 0);
			} else {
				set_time(pixels, work_time, 0, brightness, 0);
			}

			if (debounce_button(BUTTON_START) || debounce_button(RF_START)) {
				start();
			}
			break;

		case WORK:
			set_time(pixels, running_time, 0, brightness, 0);
			time_set = 1;
			// fallthrough
		case REST:
			if (!time_set) {
				set_time(pixels, running_time, brightness, 0, 0);
			}
			if (debounce_button(BUTTON_STOP) || debounce_button(RF_STOP)) {
				pause();
			}
			break;

		case PAUSE:
			if (debounce_button(BUTTON_START) || debounce_button(RF_START)) {
				resume();
			}
			if (debounce_button(BUTTON_STOP) || debounce_button(RF_STOP)) {
				reset();
				set_time(pixels, work_time, 0, brightness, 0);
			}
			break;
		}

		set_round(pixels, current_round, 0, 0, brightness);
		write_pixels(pixels, sizeof(pixels));
		_delay_ms(1);
	}

	return 0;
}

ISR(TIMER1_COMPA_vect) {
	if (running_time.minutes == 0 && running_time.seconds <= 1) {
		advance_state();
	} else if (running_time.seconds == 0) {
		running_time.minutes--;
		running_time.seconds = 59;
	} else {
		running_time.seconds--;
	}
}

ISR(TIMER0_COMPA_vect) {
	display_rest_cycles--;
	if (display_rest_cycles == 0) {
		TCCR0B &= TIMER_0_OFF;
	}
}

ISR(TIMER2_COMPA_vect) {
	buzz_cycles--;
	if (buzz_cycles == 0) {
		buzz_off();
		return;
	}
	if (buzz_alternate) {
		buzz_alternate_cycles--;
		if (buzz_alternate_cycles == 0) {
			buzz_alternate_cycles = BUZZ_ALTERNATE_MS / 10;
			PORT_BUZZ ^= (1 << PIN_BUZZ);
		}
	}
}

void start() {
	if (time_empty(work_time) && time_empty(rest_time)) {
		// We need at least one of our two periods to be greater than
		// 0, otherwise the buzzer will just run nonstop
		return;
	}


	if (time_empty(work_time)) {
		// If there's no work time set, we'll have to go straight to
		// the rest time
		running_time = rest_time;
		state = REST;
		buzz_rest();
	} else {
		running_time = work_time;
		state = WORK;
		buzz_work();
	}

	current_round = 1;
	TCCR1B |= TIMER_1_ON;
}

void pause() {
	TCCR1B &= TIMER_1_OFF;
	paused_state = state;
	state = PAUSE;
	buzz_off();
}

void resume() {
	state = paused_state;
	TCCR1B |= TIMER_1_ON;
}

void reset() {
	TCNT1 = 0;
	state = STARTUP;
	current_round = 0;
}

void advance_state() {
	if (state == WORK) {
		if (time_empty(rest_time)) {
			// If there's no rest time, just reset the work time
			// counter
			running_time = work_time;
			current_round = (current_round + 1) % 100;
			buzz_work();
		} else {
			running_time = rest_time;
			state = REST;
			buzz_rest();
		}
	} else if (state == REST) {
		current_round = (current_round + 1) % 100;
		if (time_empty(work_time)) {
			// If there's no work time, just reset the rest time
			// counter
			running_time = rest_time;
			buzz_rest();
		} else {
			running_time = work_time;
			state = WORK;
			buzz_work();
		}
	}
}

void buzz_work() {
	buzz_cycles = BUZZ_TIME_WORK_MS / 10;
	buzz_alternate_cycles = BUZZ_ALTERNATE_MS / 10;
	buzz_alternate = 1;
	PORT_BUZZ |= (1 << PIN_BUZZ);
	TCCR2B |= TIMER_2_ON;
}

void buzz_rest() {
	buzz_cycles = BUZZ_TIME_REST_MS / 10;
	buzz_alternate = 0;
	PORT_BUZZ |= (1 << PIN_BUZZ);
	TCCR2B |= TIMER_2_ON;
}

void buzz_off() {
	TCCR2B &= TIMER_2_OFF;
	PORT_BUZZ &= ~(1 << PIN_BUZZ);
}

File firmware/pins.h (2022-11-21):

/*
 * Copyright (C) 2022, Robert Bieber
 *
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
 * You should have received a copy of the GNU General Public License
 * along with this program.  If not, see
 * <https://www.gnu.org/licenses/>.
 */

#ifndef PINS_H
#define PINS_H

#include <avr/io.h>

#define SCREEN_SIZE 384

#define DDR_STATUS DDRB
#define PORT_STATUS PORTB
#define PIN_STATUS PB0

#define DDR_SCREEN DDRB
#define PORT_SCREEN PORTB
#define PIN_SCREEN PB1

#define DDR_BUZZ DDRB
#define PORT_BUZZ PORTB
#define PIN_BUZZ PB2

#define DDR_START DDRD
#define PULLUP_START PORTD
#define PORT_START PIND
#define PIN_START PD0

#define DDR_STOP DDRD
#define PULLUP_STOP PORTD
#define PORT_STOP PIND
#define PIN_STOP PD1

#define DDR_RF_START DDRD
#define PULLUP_RF_START PORTD
#define PORT_RF_START PIND
#define PIN_RF_START PD4

#define DDR_RF_STOP DDRD
#define PULLUP_RF_STOP PORTD
#define PORT_RF_STOP PIND
#define PIN_RF_STOP PD5

#define DDR_DIAGNOSTIC DDRD
#define PULLUP_DIAGNOSTIC PORTD
#define PORT_DIAGNOSTIC PIND
#define PIN_DIAGNOSTIC PD3

#define ADC_WORK_MINUTES 0
#define ADC_WORK_SECONDS 1
#define ADC_REST_MINUTES 2
#define ADC_REST_SECONDS 3
#define ADC_BRIGHTNESS 4

// Turn timer 0 on with a 1024 prescaler
#define TIMER_0_ON ((1 << CS02) | (1 << CS00))
#define TIMER_0_OFF (~((1 << CS02) | (1 << CS01) | (1 << CS00)))

// Turn timer 1 on with a 1024 prescaler
#define TIMER_1_ON ((1 << CS12) | (1 << CS10))
#define TIMER_1_OFF (~((1 << CS12) | (1 << CS11) | (1 << CS10)))

// Turn timer 2 on with a 1024 prescaler
#define TIMER_2_ON ((1 << CS22) | (1 << CS21) | (1 << CS00))
#define TIMER_2_OFF (~((1 << CS22) | (1 << CS21) | (1 << CS20)))

#endif

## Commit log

2022-10-16 Initial Commit
    This is the very beginning of the project. The firmware doesn't
    really do anything useful yet, but I have implemented WS2812B control
    in assembly for an ATTiny running at 20MHz and designed a digit and a
    colon separator to fit the LEDs into.
    [capytimer.FCStd, digit.stl, divider.stl]
2022-10-21 PCB Mount Points in 3D Models
    I'm going to use PCBs with LEDs mounted instead of manually soldering
    LED strips together, so this adds some mount points to the digit and
    diffuser 3D models to fit M3 heated inserts.
    [capytimer.FCStd, digit.stl, divider.stl]
2022-10-21 Added LEDs To Test Code
    Still nothing really notable going on in the firmware, but I bumped up
    the size of the pixel value buffer for testing with a full digit. I
    also realized that having the firmware gitignore'd also ignored the
    directory, so I just checked it in.
2022-10-21 Digit PCB Design
    This is my first iteration of the PCB design for the digits, which
    will be chained together with JST connectors. It's also my first PCB
    design ever, so absolutely no guarantees that it's any good.
    [digit-B_Cu.gbl, digit-B_Mask.gbs, digit-B_Paste.gbp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]
2022-10-23 Playing With ADC and Digits
    I'm beginning to experiment with the ADC and a couple of WS2812B
    digits. I only have two for now, so I'm just testing using
    potentiometers to set the minute components of the work and rest
    times.
    It wasn't feasible to cram a decoder for a more memory-efficient type
    of storage into the digit writing routine, so I just went ahead and
    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
2022-10-25 Counting Down
    This gets me to a point where the timer actually, well, times, albeit
    with only two digits. I've got the 16 bit counter in action to count
    off the seconds and rearranged the main loop to work as a state
    machine with some global state to make it all work with the timer
    interrupt.
2022-10-26 Starting Control Board Schematic
    This gets the control board schematic started, but not complete yet.
    [controller.kicad_pcb, controller.kicad_sch]
2022-10-31 Buzzer Tests
    Doing some initial testing with a piezo buzzer, I'll make this more
    sophisticated with one of the timers next.
    [main.c]
2022-10-31 More Controller Updates
    Continuing to work on the controller board schematic
    [controller.kicad_sch]
2022-11-01 First Draft of Control Board
    This completes the first draft of the control board schematic, adding
    the RF module inputs and the connectors for the start/stop/reset
    buttons.
    [controller.kicad_sch]
2022-11-01 Control Board PCB Layout
    This is a first stab at the PCB layout for the control board.
    [controller.kicad_pcb]
2022-11-05 Controller PCB Diagnostic Header
    This adds a diagnostic header that I'll be able to put a jumper on to
    turn on diagnostic mode--which will be used to calibrate the
    potentiometer inputs. In addition to adding this to the PCB layout, I
    rearranged a few components and cleaned up some traces.
    [controller.kicad_pcb, controller.kicad_sch]
2022-11-05 Added Capy Logo to Controller Board
    [controller.kicad_pcb]
2022-11-05 Silkscreen Cleanup
    Removed the placeholder Ref** text from the mounting holes in the
    digit and control PCBs
    [controller.kicad_pcb, digit.kicad_pcb]
2022-11-06 Test Frames and Diffuser Updates
    I reduced the height of the diffusers to 15mm for better brightness,
    and added models for some frames to hold the digits for testing.
    [capytimer.FCStd, digit.stl, divider.stl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]
2022-11-06 Added Volume Control
    This adds a volume control potentiometer to the schematic and PCB
    design for the control board
    [controller.kicad_pcb, controller.kicad_sch]
2022-11-06 Firmware Cleanup
    I've got all the test hardware set up now, so at this point it's time
    to stop toying around with demo code and start writing a serious
    firmware. To that end, I made a handful of enhancements here that
    shouldn't materially affect the behavior:
    * Added missing copyright headers
    * Defined constants for all of the I/O pins
    * Added a `setup` function instead of dumping all the setup in `main`
    * Combined `debounce_start` and `debounce_stop` into a single
    `debounce_button` function that handles the button I/O as well
    * Pulled ADC reading out into a separate function
    * Removed duplicate `WORK`/`REST` state logic with a fallthrough in
    the switch
    The main loop also seemed to be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
    [adc.c, debounce.c, main.c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]
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2022-11-07 Buzzer Implementation
    This replaces the old, somewhat janky buzzer implementation with
    something closer to how I want the final product to behave with an
    alternating buzz for starting the work time and a solid one for
    starting the rest time. I also handled the edge cases when the timer
    runs with either the rest or the work time set to zero, in which case
    we just repeat the one time that is set over and over again.
    [main.c, pins.h]
2022-11-08 Added MOSFET to Controller Board for Buzzer
    I want to allow the use of some higher powered piezo buzzers, so this
    adds a MOSFET to switch the buzzer current instead of connecting it
    directly to the Atmega pin.
    [controller.kicad_pcb, controller.kicad_sch]
2022-11-09 Added Separator PCB And Build Files
    This adds a simple PCB with 2 WS2812B LEDs for the center separator.
    I also generated gerber, BOM and pick and place files for all the
    boards and updated the part numbers for the WS2812B LEDs to the new
    version that JLCPCB carries.
    [controller-B_Cu.gbl, controller-B_Mask.gbs, controller-B_Paste.gbp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]
2022-11-10 Adjustable Brightness
    This adds an ADC input (hooked up to a potentiometer) to set the
    display brightness in five separate levels. For the debounce function
    I manually set a series of thresholds, which is a model I'll be moving
    all of the ADC debounce functions to in the next couple of commits as
    it enables profiling a potentiometer with a non-linear response. I
    also noticed that I'd accidentally left some `else if (0)` blocks in
    the other debounce functions from debugging a while back and removed
    them, which has improved the stability of the minute and second
    potentiometers as well.
    [debounce.c, main.c, pins.h]
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2022-11-13 PCB Touchup
    Two changes in this commit.
    1. I rewired the volume potentiometer so that the MOSFET is now the
    closest thing to ground. That way we'll always be sure to have
    sufficient gate-source voltage to trigger it when the buzzer is turned
    on.
    2. I added v1/date indicators to the silk screen layers of all the
    PCBs.
    [controller-B_Cu.gbl, controller-B_Mask.gbs, controller-B_Paste.gbp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]
2022-11-20 Debounce Refactor and RF Button Addition
    This adds pins for and checks an RF receiver for use as a remote
    control. Along the way I refactored the button debouncing so that
    buttons will now fire once and not fire again until they've fully
    reset. This is used for all buttons now and obviates the check for
    button release after pause.
    [debounce.c, main.c, pins.h]
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2022-11-21 Bump Up LED Resistors
    The LEDs on the controller board are very bright in the first batch of
    boards, so this replaces the 470ohm resistors with 1k resistors to dim
    them a little.
    [controller-B_Cu.gbl, controller-B_Mask.gbs, controller-B_Paste.gbp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]
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2022-11-27 Added Remote PCB
    This adds a simple little PCB design to mount a QIACHIP 433Mhz
    transmitter and connect it to a couple of buttons and an antenna. I
    used through-hole resistors in this board because it just didn't make
    sense to pay for SMT assembly when the two resistors are the only
    components on the board.
    [remote-B_Cu.gbl, remote-B_Mask.gbs, remote-B_Paste.gbp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]
2022-11-28 Enclosure SVG Updates
    Two fixes here. First, I updated the digit segment cutouts to use
    inside line cuts. I also added a custom anchor point to the front
    template, so you can grid off of the digit cutouts at the top left and
    not have to do any math to get the text aligned properly.
2022-12-03 Remote PCB Update
    This updates the remote control PCB to use tactile switches directly
    on the board instead of buttons connected via JST connector.
    [remote-B_Cu.gbl, remote-B_Mask.gbs, remote-B_Paste.gbp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]
2022-12-04 Started Working on Remote Design
    I'm just getting started putting together a remote that will connect a
    QIACHIP transmitter to a couple of buttons and a 9v battery. This
    adds just the top half of the shell.
    [remote.FCStd]
2022-12-05 Continuing Remote Work
    This adds a bottom portion and battery holder to the remote control
    design with the battery lid beginning to take shape.
    [bottom.stl, remote.FCStd]
2022-12-06 Added Remote Battery Lid
    This adds the battery lid with magnets for the remote control. At
    this point the design should be functional, however it feels very
    awkward in the hand and I think I'm going to redesign it for a pair of
    AAA batteries instead.
    [remote.FCStd]
2022-12-06 Remote AAA Redesign: Top
    This is the first part of a remote control redesign to use two AAA
    batteries instead of one 9v. This includes an updated top component
    with a battery compartment built in.
    [remote.FCStd]
2022-12-07 AAA Remote v1
    This is the first full design of the AAA-based remote control. I've
    tested the fit with the threaded inserts and screws and magnets, but
    I'm still waiting on the battery contacts and PCBs to arrive and may
    need to change the design slightly to accommodate them.
    [bottom.stl, remote.FCStd, top.stl]
2022-12-10 Fix Discontinuities in Enclosure Cut File
    The FreeCAD export I used to lay out the cut paths for the seven
    segment digits had a bunch of open paths for the actual segments. For
    some reason the Origin *mostly* took these paths in stride, but a few
    of them would show up as on line cuts instead of inside cuts on the
    device and need manual correction. This fixes the paths so they
    should cut correctly by default.
2022-12-11 Rotated Remote Top
    This includes a new STL file for the top component of the remote that
    doesn't require manual rotation when slicing. At this point the
    components all appear to fit in the remote, so I think this is going
    to be the final design. Ideally I'd like to tweak the battery
    compartment a little more, but I've made such a mess referencing
    external geometry that it's just too difficult to make those kinds of
    changes at this point.
    [remote.FCStd, top.stl]
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2022-12-22 Remove Remote Screws
    Since it's so easy to break off the stems by overtightening the remote
    screws, I'm removing the holes for them from the back. The board will
    still screw down to the top piece, but sealing up the shell will be
    done with super glue now. This isn't ideal for repairability, but
    should hold up better in practice.
    [lid.stl, remote.FCStd, top.stl]
2022-12-23 Restored Missing Fillet
    [lid.stl, remote.FCStd, top.stl]
2022-12-29 STL Fixup
    I mixed up the STL files when exporting after the last change, this
    should get the remote files all sorted out.
    [bottom.stl, top.stl]

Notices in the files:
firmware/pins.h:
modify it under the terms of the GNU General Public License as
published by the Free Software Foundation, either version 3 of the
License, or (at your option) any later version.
